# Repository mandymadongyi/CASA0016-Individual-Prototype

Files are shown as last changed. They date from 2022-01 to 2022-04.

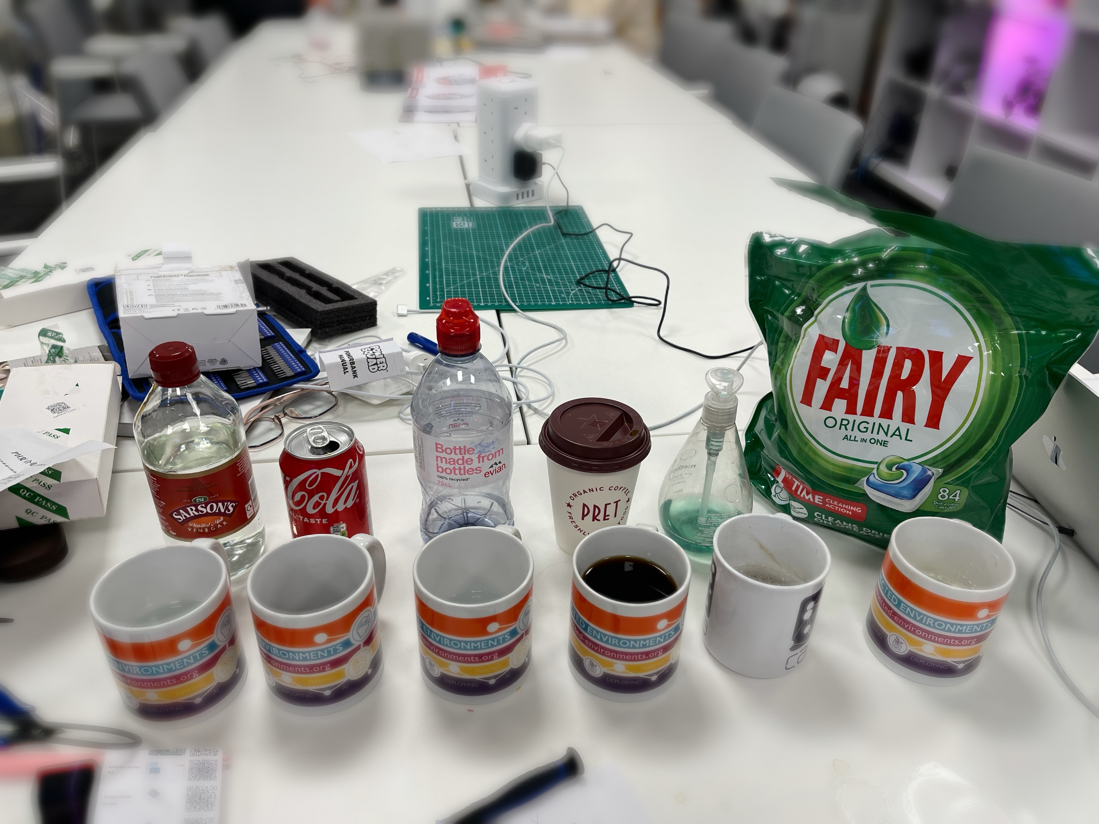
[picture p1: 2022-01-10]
Pictures/Figure 4. Calibrate PH sensor with vinegar, coke, water, coffee, liquid soap and laundry liquid.JPG

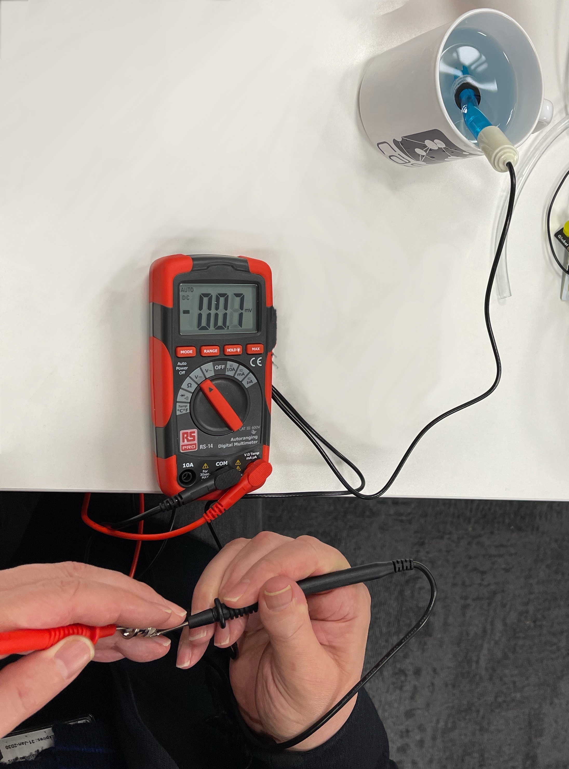
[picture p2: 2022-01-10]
Pictures/Figure 5. The alkaline solution (liquid soap) outcomes a small and negative value (-0.7 mV) when using multimeter to measure the voltage at sensor probe.JPG

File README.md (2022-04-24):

CASA0016 Project Report

River Monitoring System

Dongyi Ma 

January 2022

#  

# Introduction 

Rivers are a critical but generally under-researched environment since they are distributed throughout the wild and not easily accessible. Rivers are essential as changes in water features also indicate climate movements and landscape changes. To better understand our environment, a sensor-based river monitoring system is designed to provide remote access to real-time information about the river without heading to the riverside to check its’ condition. While most existing watering monitoring systems can only visualise data locally without storing historical data, or merely use one or two sensors, the motivation of this project is to build a river monitoring system, lightweight and intelligent, that measures the water level, PH value and temperature, then keep tracking and analysing sensor data by visualising real-time data locally on LCD at the riverside and also remotely using raspberry pi and Grafana dashboard display. This report documents the design, build and functionality of the prototype in Design and Build and reflects on challenges, key learnings, critical feedbacks, and future work in Reflection. 

# Project Goals

This prototype explores the potential of remote monitoring environmental data and recording the changes of rivers (water level, water temperature and PH value) using multiple types of sensors, allowing us to better understand the real-time condition of the river and its tendencies. 

# Design and Build

## Design rationale 

### Collecting data

#### Measurement for Water Temperature 

[Connect temperature sensor to Arduino board](https://arduinogetstarted.com/tutorials/arduino-temperature-sensor) (Arduino - Temperature Sensor | Arduino Tutorial, 2022) to collect real-time water temperature data.

#### Measurement for Water Level 

[Connect ultrasonic sensor to Arduino board](https://arduinogetstarted.com/tutorials/arduino-ultrasonic-sensor)  (Arduino - Ultrasonic Sensor | Arduino Tutorial, 2022) to collect the distance between the ultrasonic sensor and the object. If the elevation of the sensor is h, the distance measured by the ultrasonic sensor is d, then

Water Level = h – d (meters)

#### Measurement for PH value 

[Connect PH sensor to Arduino board](https://github.com/mandymadongyi/CASA0016-Individual-Prototype/blob/main/References/User Manual PH Sensor.pdf) (CASA0016-Individual-Prototype/User Manual PH Sensor.pdf at main · mandymadongyi/CASA0016-Individual-Prototype, 2022) to collect real-time voltage data at Arduino’s analogue pin, then convert the analogue signal into PH value. According to the millivolts to pH formula discovered by Dr Jerry Tennant, PH number follows a simple linear relationship with the millivolts in the liquid, where the full range of pH scale goes from a low acidic pH 0 = +400 mV to a high alkaline pH 14 = -400 mV level. (pH Voltage | Acidity, Alkalinity equals Volts calculator, 2022)



Figure 1. PH and mV mapping (pH Voltage | Acidity, Alkalinity equals Volts calculator, 2022)

### Data Aggregation and Visualisation

To aggregate and consume collected data for tracking and analysing, the following steps are needed.

#### Local visualisation 

[Connect LCD to Arduino board](https://arduinogetstarted.com/tutorials/arduino-ultrasonic-sensor-lcd) (Arduino - Ultrasonic Sensor - LCD | Arduino Tutorial, 2022) to display water temperature, level, PH value at the riverside.

#### Remote visualisation 

After collecting data, [Connect the device to Wi-Fi and MQTT](https://docs.arduino.cc/tutorials/uno-wifi-rev2/uno-wifi-r2-mqtt-device-to-device) (Arduino-uno-wifi-rev2-mqtt-device-to-device| Arduino Tutorial, 2022) to transmit sensor data for aggregation. Store data in influx database in a raspberry pi microcontroller, and then visualise on Grafana dashboard.  (cetools.org| CASA0014 Plant-Monitor Tutorial, 2022). 

## Building Process

### Part List

**
**

·     Board:

  [Arduino Uno Wi-Fi Rev2](https://www.arduino.cc/en/Guide/ArduinoUnoWiFiRev2)

·     Sensors: 

•    [DS1820B One-wire Water Temperature Sensor ](https://datasheets.maximintegrated.com/en/ds/DS18B20.pdf) 

•    [Arduino Ultrasonic Sensor ](https://cdn.sparkfun.com/datasheets/Sensors/Proximity/HCSR04.pdf) 

•    [E-201-C PH Sensor](https://github.com/e-Gizmo/PH-Sensor-E-201-C/blob/master/PH Sensor E-201-C.pdf) 

·     Actuator:

     [RGB 16x2 LCD Display ](https://www.arduino.cc/documents/datasheets/LCDscreen.PDF)

·      Power Supply:  

  [Power Squad Power Bank ](https://www.amazon.co.uk/Power-Squad-POWSQHM05-PowerSquad-Powerbank-Black/dp/B07VXQ8CFR) 

·     Data Aggregation:    

 [Raspberry Pi 4 Computer ](https://datasheets.raspberrypi.com/rpi4/raspberry-pi-4-datasheet.pdf)

-  Software:

•    [Arduino IDE](https://www.arduino.cc/en/software) 

•    [MQTT Explorer](http://mqtt-explorer.com/) 

•    [Raspberry Pi Imager](https://www.raspberrypi.com/software/) 

•    [Grafana](https://grafana.com/) 

•    [Fusion 360](https://www.autodesk.co.uk/products/fusion-360/overview)

•    [Prusaslicer](https://www.prusa3d.com/page/prusaslicer_424/)  

### Circuit

The prototype is based on one Arduino microcontroller, three sensors and one LCD connected in parallel. The schematic of the circuit is shown below.



Figure 2. Schematic of the circuit



Figure 3. Real wiring

### Calibration

The DS1820B temperature and ultrasonic sensors are already calibrated to fetch temperature and distance data directly.

Much effort has been put into calibrating the PH sensor since the analogue signal generated from the sensor probe is too small, and the voltage for alkaline solutions are negative numbers, which are not able to be read by Arduino analogue pin and converted into solid PH value. To get meaningful readings, a PCB board is used to pre-process data before the probe sending signals to the analogue pin and Arduino by doing: 1. [Level shift the detected voltage ](https://daycounter.com/Circuits/OpAmp-Level-Shifter/OpAmp-Level-Shifter.phtml) (Non-Inverting Op-Amp Level Shifter - Daycounter, 2022) so that all readings are positive numbers and 2. amplify the shifted signal by three times. Then, the linear function between PH and mV will be defined by calibrating with various acid and alkaline solutions.



Figure 4. Calibrate PH sensor with vinegar, coke, pure water, coffee, liquid soap and laundry liquid



Figure 5. The alkaline solution (liquid soap) outcomes a small and negative value (-0.7 mV) when using a multimeter to measure the voltage at the sensor probe

#### Amplify the original millivoltage signal and level shift up using PCB board

The PCB board contains a voltage follower circuit and a non-inverting amplifier. 

For the voltage follower circuit, suppose the resistance of the potentiometer is Rx kΩ, according to the voltage divider rule (Monk, 2017, p20), 

The shifted voltage Vout = Vin + Rx * V/R2        (Equation 1)

Where V= 2.5V and R2 = 5.1kΩ

For the non-inverting amplifier, we have

Vout = Vin * (1+R2/R1)  (Monk, 2017, p322)

Where R2 = R4 = 20kΩ, R1 = R 5 = 10kΩ

Thus, Vout = 3 * Vin              (Equation 2)

Combining the equation1 and 2, the input and output voltage of PCB should follow this relationship:

Vout = 3 * ( Vin + 0.49 * Rx)      (Equation 3)

A 50kΩ potentiometer is used in this project.  



Figure 6. PCB board circuit for PH sensor (CASA0016-Individual-Prototype/User Manual PH Sensor.pdf at main · mandymadongyi/CASA0016-Individual-Prototype, 2022)

#### Converting Voltage to PH 

#### Since voltage value is pre-processed for Arduino, Figure 1 mapping is no longer valid to convert PH value from voltage. Thus, a liner function is required to do the converting. Suppose the PH value of vinegar, water, and soap liquid for the experiment are 2.5, 7.0 and 10.0, respectively.

Based on analogue input from Arduino serial plotter, PH 2.5 liquid outcomes 610mV, while PH 7 liquid outcomes 480mV. Assume PH = a * voltage + b, then 

2.5 = 610 * a + b 

7.0 = 480 * a + b

Thus PH = -0.03461518 * voltage + 23.6153846 (Equation 4)

The lab also observed that PH 10 liquid outcomes 382mV approximately fit the prediction from Equation 4 (393.3356mV), proving the liner function valid.  



Figure 7. Fitting equation and a line graph of the linear relation between PH and voltage

### Basic Sketch

[Here](https://github.com/mandymadongyi/CASA0016-Individual-Prototype/blob/main/Code/final_to_upload/final_to_upload.ino) is the link to a basic standalone Arduino sketch that monitors and visualises the water features, incorporating the earlier calibration. In addition, it can be reused by adding more sensors like water turbidity or changing transmit protocols, including Bluetooth/LoRa/HTTP, as extensions. 



Figure 8. Calculating water level and temperature, PH value and print on LCD



Figure 9. Connecting and Sending data to MQTT



Figure 10. Telegraf configuration in influx DB in raspberry pi for Grafana display

## Wrapping up

An enclosure model is designed using Fusion 360, and 3D printed out for the system. On the bottom, front and top surfaces, there are holes for the ultrasonic sensor, LCD screen, sensor probes and power bank USB cable respectively. There are two holes on the side of the box for transport. 



Figure 11. 3D Model of the enclosure



Figure 12. 3D printed box with feet made from recycled materials (cupboard and plastic bottle tops) to protect the bottom ultrasonic sensor when placing on the floor

## Prototype Demonstration 

[Here](https://youtu.be/6DnR-BQpXQE) is a link to a video demonstrating how the system works. 



Figure 13. Final prototype



Figure 14. Grafana Visualisation

# Reflection and limitations

Overall, this device works well with remotely tracking and visualising water level, temperature, and PH value data and is somehow ready to be distributed in the wild. Lessons learnt regarding calibrating sensors, packaging and developing systems with a mix of actuators plus a range of sensors are precious.  Limitations exist since standard PH calibration liquid is absent for accurate PH value, and the PH sensor user manual is not detailed enough to provide reliable measurement, calibration has to be repeated every week. The 3D printed enclosure offers less protection than IP-rated enclosures when deploying at the riverside. Besides, the power budget is crucial to ensure the device is self-managing and survives in the wild.

## Challenges and Key Learnings



Figure 15. Summary of key challenges and solutions

## Limitations

#### Power budget 

The power budget is an essential concession of a self-managing and long-time survival device when deploying in the wild. In the lab, the system's total power consumption is calculated using the bench power supply, which indicates 95mA and 73mA current when using MQTT or not. Take the average number 84 mA for estimation, the system runs approximately 30 hours since it uses a 5 Volt battery with capacity of 2500 mAh. As the water features won’t change as frequently as per second, the frequency of sending data through MQTT can be adjusted to lower down power budget.

Besides, a PIR motion sensor is useful for controlling the LCD screen, only turning it on when someone is around. Lora and large capacity batteries are also helpful to ensure longer endurance time.









Figure 16. Measuring current when sending MQTT data

Figure 17. Measuring current when not sending MQTT data

Figure 18. Measuring current when sensors are not working

Figure 19. Measuring current when sensors are not working and LCD turned off

### Data Accuracy 

Data accuracy cannot be guaranteed in large-scale sensor devices since no battery is perfect for providing a constant 5V supply to each sensor. Also, Package dropping happens in internet transmitting. For PH sensor, current calibration might not be solid for long-term use. However, data accuracy can be improved by testing three times and choosing the average number as output.

## Future potentialities

#### Data Visualisation

Other visualisation tools (Echart, RAWGraphs, ChartBlocks, Tableau etc.) are recommended in the future. The Grafana dashboard is not fully utilised [[MI1\]](#_msocom_1) in this project yet, leaving a potential of exploring more features of Grafana, including tracking, analysing time-series databases and wrapping up outcomes into insightful reports and websites.  

#### System Design 

When sensing water level, the reflection of sunlight and passing boats may cause inaccurate readings. The ultrasonic sensor detection area is only 4 meters, so better design is needed to improve water level sensing. Also, it’s better to separate water quality and level into two parts since only PH and water temperature sensors have probes to go into the water.

# Reference:

\1.   Arduino Getting Started. 2022. *Arduino - Temperature Sensor | Arduino Tutorial*. [online] Available at: <https://arduinogetstarted.com/tutorials/arduino-temperature-sensor> [Accessed 3 January 2022].

\2.   Arduino Getting Started. 2022. *Arduino - Ultrasonic Sensor | Arduino Tutorial*. [online] Available at: <https://arduinogetstarted.com/tutorials/arduino-ultrasonic-sensor> [Accessed 3 January 2022].

\3.   GitHub. 2022. *CASA0016-Individual-Prototype/User Manual PH Sensor.pdf at main · mandymadongyi/CASA0016-Individual-Prototype*. [online] Available at: <https://github.com/mandymadongyi/CASA0016-Individual-Prototype/blob/main/References/User%20Manual%20PH%20Sensor.pdf> [Accessed 3 January 2022].

\4.   Traditionaloven.com. 2022. *pH Voltage | Acidity, Alkalinity equals Volts calculator*. [online] Available at: <https://www.traditionaloven.com/conversions_of_measures/ph-voltage.html> [Accessed 3 January 2022].

\5.   Arduino Getting Started. 2022. *Arduino - Ultrasonic Sensor - LCD | Arduino Tutorial*. [online] Available at: <https://arduinogetstarted.com/tutorials/arduino-ultrasonic-sensor-lcd> [Accessed 3 January 2022].

\6.   Docs.arduino.cc. 2022. [online] Available at: <https://docs.arduino.cc/tutorials/uno-wifi-rev2/uno-wifi-r2-mqtt-device-to-device> [Accessed 3 January 2022].

\7.   Workshops.cetools.org. 2022. *Plant-Monitor*. [online] Available at: <https://workshops.cetools.org/codelabs/CASA0014-2-Plant-Monitor/index.html?index=..%2F..casa0014#12> [Accessed 3 January 2022].

\8.   Daycounter.com. 2022. *Non-Inverting Op-Amp Level Shifter - Daycounter*. [online] Available at: <https://daycounter.com/Circuits/OpAmp-Level-Shifter/OpAmp-Level-Shifter.phtml> [Accessed 8 January 2022].

\9.   Monk, S., 2017. *Electronics cookbook*. 1st ed. " O'Reilly Media, Inc.".

------

 [[MI1\]](#_msoanchor_1)*utilized

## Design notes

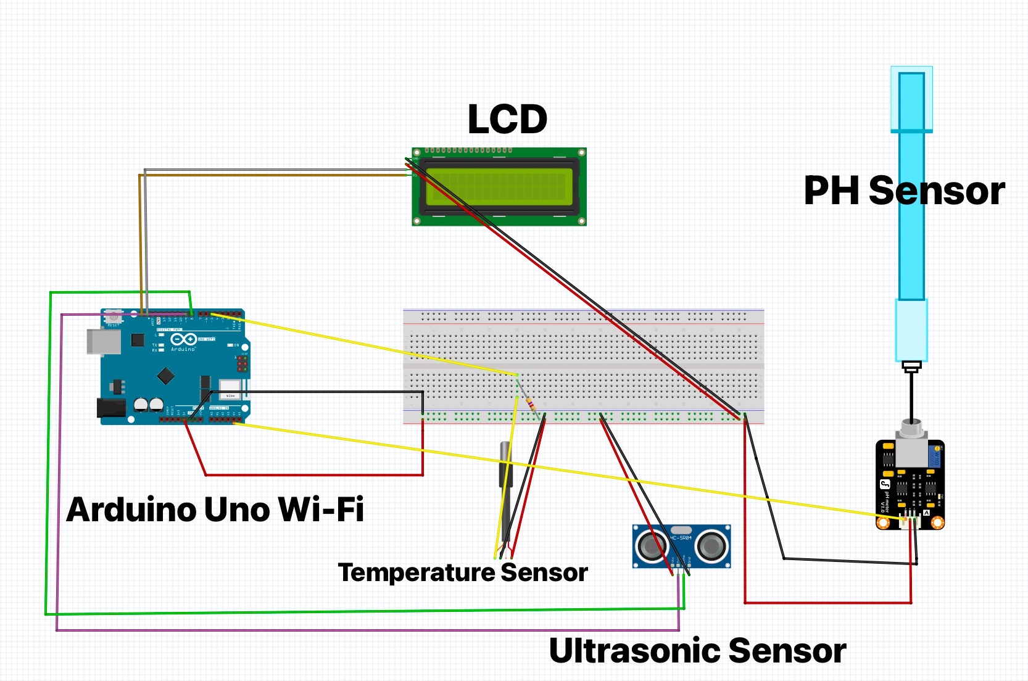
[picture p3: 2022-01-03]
Pictures/Figure 2. Schematic of the circuit.JPG

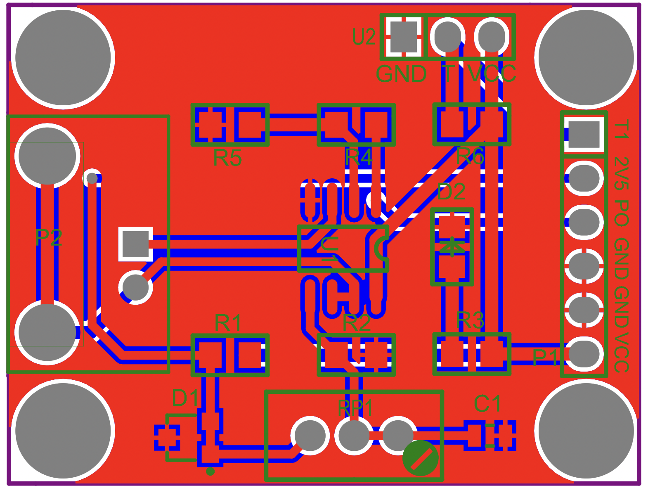
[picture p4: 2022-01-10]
Pictures/PCB Board Specification.png

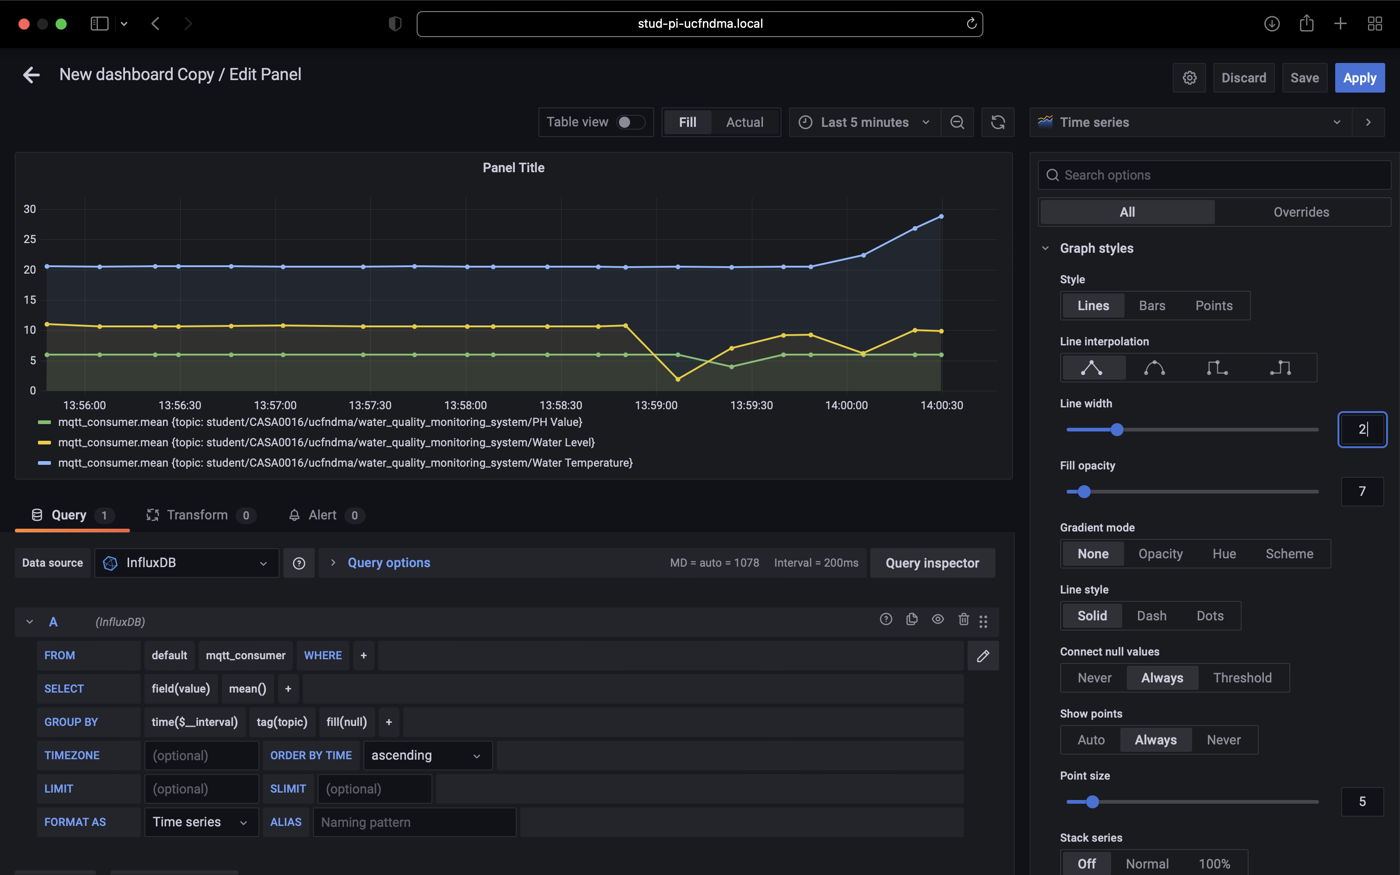
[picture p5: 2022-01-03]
Pictures/Figure 14. Grafana Visualisation.png

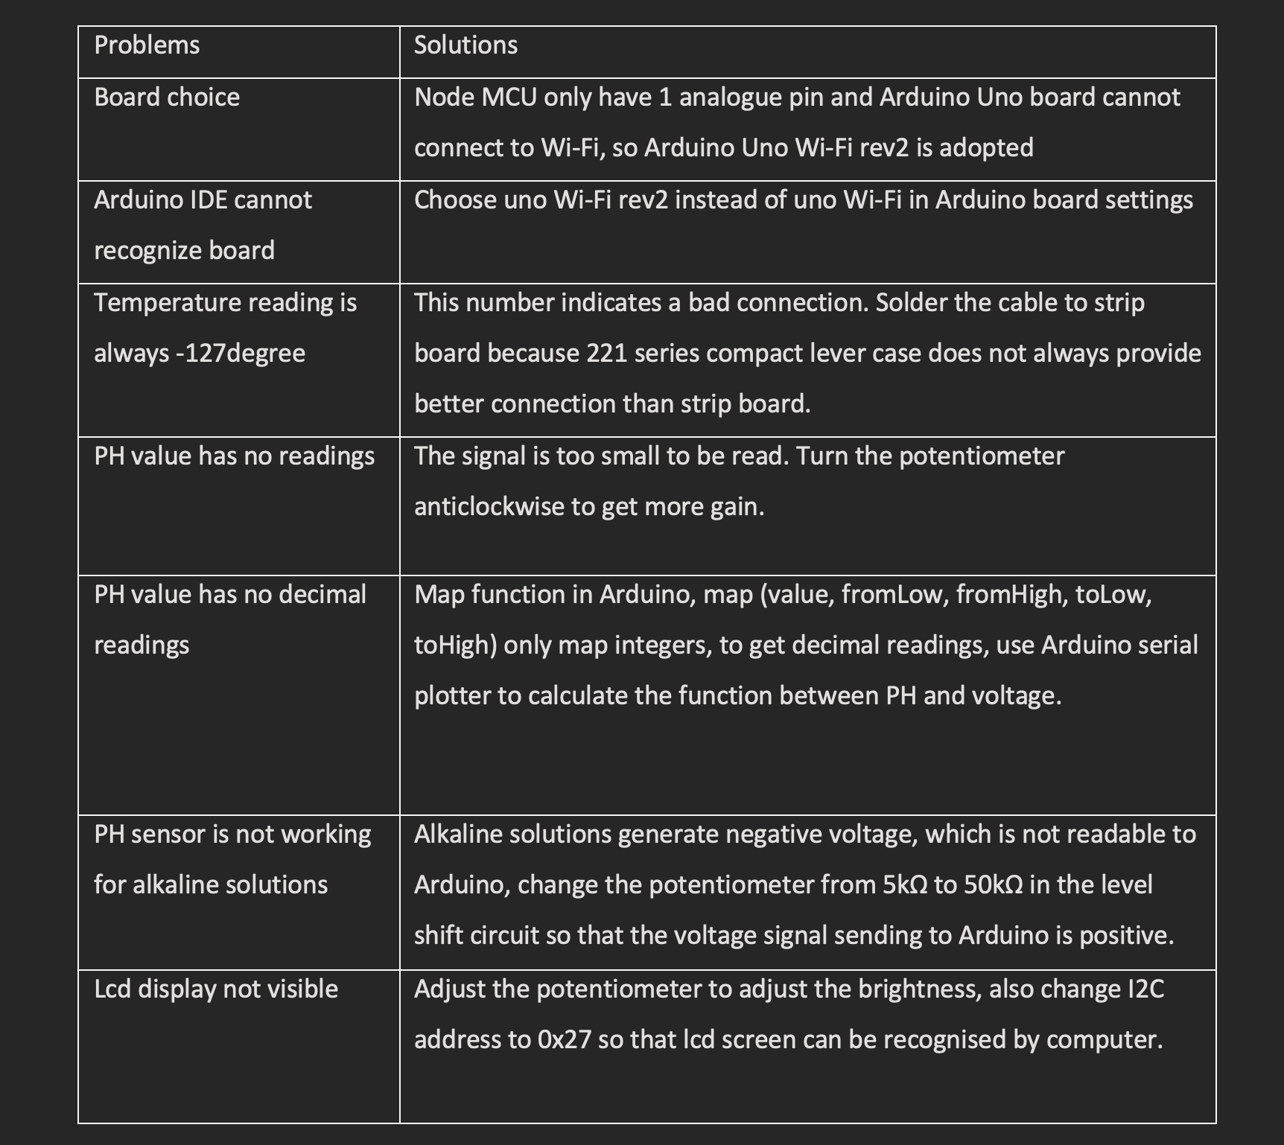
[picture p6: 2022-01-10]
Pictures/Figure 15. Summary of key challenges and solutions.png

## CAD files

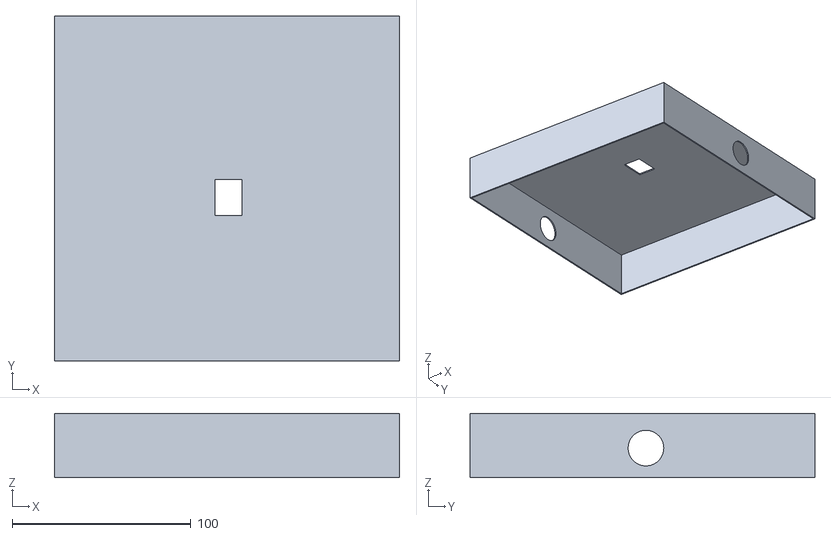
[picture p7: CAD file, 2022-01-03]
Enclousure/Body2.stl
193.3 x 193.0 x 36.0

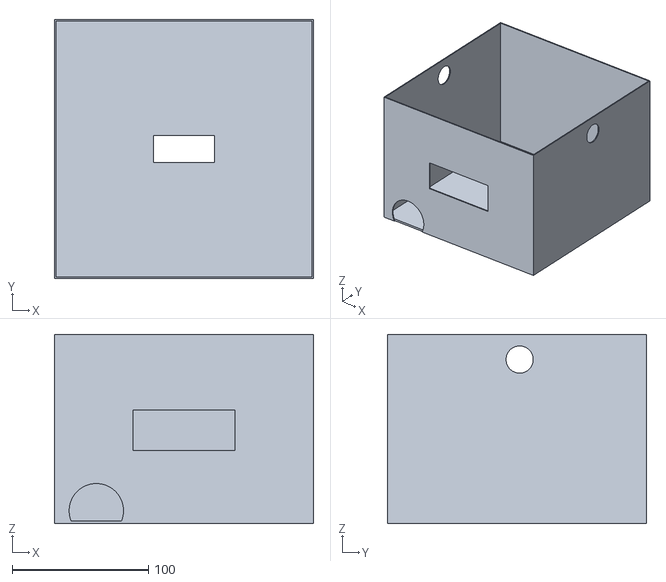
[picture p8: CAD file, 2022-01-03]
Enclousure/finalfinal.stl
190.3 x 190.0 x 139.0

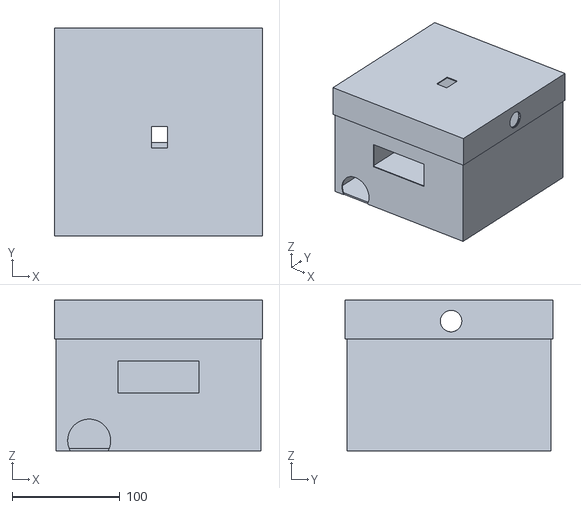
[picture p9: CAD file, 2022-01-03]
Enclousure/finalcase v0.stl
193.3 x 193.0 x 140.0

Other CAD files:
Enclousure/Body1.stl
Enclousure/case111 v1.stl

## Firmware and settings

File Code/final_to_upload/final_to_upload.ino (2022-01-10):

// water quality monitoring - water level, temperature, ph
// Dongyi Ma  Dec 2021
// start by showing info on lcd, then add ultrasonic sensor for water level meseasuring, then add DS18B20 sensor to meseaure water temperature, and then add ph sensor to detect ph vluae of the liquid
// show the three sensed data locally on lcd and push to mqtt for remote sensing




#include <LiquidCrystal_I2C.h>   // lcd library
#include <OneWire.h>    // water tem library  part 1
#include <DallasTemperature.h>    // water library part2
#include <ArduinoMqttClient.h>  // mqtt library part 1
#include <WiFiNINA.h>       // mqtt library part 2  
#include "GuessWhat.h"    //password file needs to be removed before uploading to github


//below part sets up lcd
LiquidCrystal_I2C lcd(0x27, 16, 2); // I2C address 0x27 16 column and 2 rows


// below part sets up ultrasonic sensor for water level
int trigPin = 9;    // TRIG pin
int echoPin = 8;    // ECHO pin
int h = 17; // the height above sea level of the ultrasonic sensor for measuring the water level
float duration_us, distance_cm, level;

//below part sets up DS18B20 sensor for water temperature
const int SENSOR_PIN = 5; // Arduino pin connected to DS18B20 sensor's DQ pin
OneWire oneWire(SENSOR_PIN);         // setup a oneWire instance
DallasTemperature tempSensor(&oneWire); // pass oneWire to DallasTemperature library
float tempCelsius;    // temperature in Celsius


//below part sets up analoge input votage for liquid ph
#define SensorPin A0   // ph input


//below part sets up mqtt sender configuartion

///////please enter your sensitive data in the Secret tab/arduino_secrets.h
char ssid[] = SECRET_SSID;        // your network SSID (name)
char pass[] = SECRET_PASS;    // your network password (use for WPA, or use as key for WEP)

char mqttuser[] = SECRET_MQTTUSER;
char mqttpass[] = SECRET_MQTTPASS;
WiFiClient wifiClient;
MqttClient mqttClient(wifiClient);

const char broker[] = "mqtt.cetools.org";
int        port     = 1884;
const char topic1[]  = "student/CASA0016/ucfndma/water_quality_monitoring_system/Water Level";

const char topic2[]  = "student/CASA0016/ucfndma/water_quality_monitoring_system/Water Temperature";

const char topic3[]  = "student/CASA0016/ucfndma/water_quality_monitoring_system/PH Value";


//set interval for sending messages (milliseconds)
const long interval = 8000;
unsigned long previousMillis = 0;

int count = 0;

void setup() {
  //lcd initialization
  lcd.init();               // initialize the lcd
  lcd.backlight();          // open the backlight

  //ultrasonic initialization
  pinMode(trigPin, OUTPUT); // config trigger pin to output mode
  pinMode(echoPin, INPUT);  // config echo pin to input mode
  Serial.begin(9600);

  //DS18B20 initialization
  tempSensor.begin();    // initialize the temp sensor

  //mqtt initialization

  //Initialize serial and wait for port to open:
  Serial.begin(9600);
  while (!Serial) {
    ; // wait for serial port to connect. Needed for native USB port only
  }

  // attempt to connect to Wifi network:
  Serial.print("Attempting to connect to WPA SSID: ");
  Serial.println(ssid);
  while (WiFi.begin(ssid, pass) != WL_CONNECTED) {
    // failed, retry
    Serial.print(".");
    delay(5000);
  }
  mqttClient.setUsernamePassword(mqttuser, mqttpass);
  Serial.println("You're connected to the network");
  Serial.println();

  Serial.print("Attempting to connect to the MQTT broker: ");
  Serial.println(broker);

  if (!mqttClient.connect(broker, port)) {
    Serial.print("MQTT connection failed! Error code = ");
    Serial.println(mqttClient.connectError());

    while (1);
  }

  Serial.println("You're connected to the MQTT broker!");
  Serial.println();
}


void loop() {
  //below part measures water level
  // generate 10-microsecond pulse to TRIG pin

  digitalWrite(trigPin, HIGH);
  delayMicroseconds(10);
  digitalWrite(trigPin, LOW);

  // measure duration of pulse from ECHO pin
  duration_us = pulseIn(echoPin, HIGH);

  distance_cm = 0.017 * duration_us; //equation used to measure distance since length equals to speed times time
  level = h - distance_cm; // calculate the water level by taking the distance out of the height above sea level of ultrasonic sensor


  //below part measures temp

  tempSensor.requestTemperatures();             // send the command to get temperatures
  delay(1000);
  tempCelsius = tempSensor.getTempCByIndex(0);  // read temperature in Celsius


  //below part measures ph value using mapping and equaltion. mapping only shows integers.
  //the equaltion is calculated by hand while there is a 400mV level up and 0mV corresponds to PH 14 and 800 mV corresponds to PH 0.

  float v = analogRead(A0);
  float PH = -0.03461518 * v + 23.6153846;
  Serial.println(v);

  Serial.println(PH);


  //below part displays data locally on lcd order is differnet because lcd space is limited

  lcd.clear();
  lcd.setCursor(0, 0); //move the cursor to the first bit of the first line
  lcd.print("T=");  //use "" for texts, blank space also matters
  lcd.print(tempCelsius);
  lcd.print("C "); // don't forget the unit
  lcd.print("PH=");
  lcd.print(PH);
  lcd.setCursor(0, 1);//the first bit of the second line
  
 

 // lcd.setCursor(5, 1); // the 6 bit of the second line since ph and lvl will share one line space
  lcd.print("Level=");
  lcd.print(level);
  lcd.print("cm");
  delay(500);

  //below part visualize data remotely on mqtt
  // call poll() regularly to allow the library to send MQTT keep alive which
  // avoids being disconnected by the broker
  mqttClient.poll();

  unsigned long currentMillis = millis();

  if (currentMillis - previousMillis >= interval) {
    // save the last time a message was sent
    previousMillis = currentMillis;

    //record random value from A0, A1 and A2
    int Rvalue = analogRead(A0);


    Serial.print("Sending message to topic: ");
    Serial.println(topic1);
    Serial.println(Rvalue);

    // send message, the Print interface can be used to set the message contents
    mqttClient.beginMessage(topic1);
    mqttClient.print(level);
    mqttClient.endMessage();

    mqttClient.beginMessage(topic2);
    mqttClient.print(tempCelsius);
    mqttClient.endMessage();

    mqttClient.beginMessage(topic3);
    mqttClient.print(PH);
    mqttClient.endMessage();

  }


}

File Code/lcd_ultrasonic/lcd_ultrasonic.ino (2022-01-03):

//lcd and ultrasonic and fake ph

#include <LiquidCrystal_I2C.h>

LiquidCrystal_I2C lcd(0x27, 16, 2); // I2C address 0x27 16 column and 2 rows

int trigPin = 9;    // TRIG pin
int echoPin = 8;    // ECHO pin
#define SensorPin A0   

float duration_us, distance_cm;

void setup() {
  lcd.init();               // initialize the lcd
  lcd.backlight();          // open the backlight 
  pinMode(trigPin, OUTPUT); // config trigger pin to output mode
  pinMode(echoPin, INPUT);  // config echo pin to input mode
  Serial.begin(9600);  
  Serial.println("pH meter experiment!"); 
}


void loop() {
  // generate 10-microsecond pulse to TRIG pin
  digitalWrite(trigPin, HIGH);
  delayMicroseconds(10);
  digitalWrite(trigPin, LOW);

  // measure duration of pulse from ECHO pin
  duration_us = pulseIn(echoPin, HIGH);

  // calculate the distance
  distance_cm = 17 - 0.017 * duration_us;
  // ph value
  int v = analogRead(A0);
  int Ph = map(v,0,100,7,0);
  Serial.println(v);
  Serial.println(Ph);
  delay(1000);
  lcd.clear();
  lcd.setCursor(0, 0); // start to print at the first row
  lcd.print("Deepth ");
  lcd.print(distance_cm);
  lcd.print("cm");
  lcd.print("   ");
  lcd.setCursor(0, 1);
  lcd.print("PH value  ");
  lcd.print(Ph);
  Serial.println(distance_cm);
  delay(500);
}
